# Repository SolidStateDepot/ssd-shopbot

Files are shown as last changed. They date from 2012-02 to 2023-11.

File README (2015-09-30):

Boulder Engineering Studio Shopbot - LinuxCNC config notes

The BES Shopbot is based on a Shopbot PRS-Alpha 96x60.  The Shopbot
Assembly Manual is here:

    http://www.shopbotdocs.com/PRS-Assembly-Manual.html

The BES Shopbot is an XYZX gantry machine.  All four joint motors are
steppers with encoder feedback.

The BES Shopbot uses a Mesa 5i23.  It uses three daughter cards:

P2: 7i47 (12-channel RS-422 serial communication interface)

    IO 000 (P2-01): StepGen #0, pin Step (Output)
    IO 001 (P2-03): StepGen #0, pin Direction (Output)
    IO 002 (P2-05): StepGen #1, pin Step (Output)
    IO 003 (P2-07): StepGen #1, pin Direction (Output)
    IO 004 (P2-09): Encoder #0, pin A (Input)
    IO 005 (P2-11): Encoder #2, pin A (Input)
    IO 006 (P2-13): Encoder #0, pin B (Input)
    IO 007 (P2-15): Encoder #2, pin B (Input)
    IO 008 (P2-17): Encoder #0, pin Index (Input)
    IO 009 (P2-19): Encoder #2, pin Index (Input)
    IO 010 (P2-21): Encoder #1, pin A (Input)
    IO 011 (P2-23): Encoder #3, pin A (Input)
    IO 012 (P2-25): Encoder #1, pin B (Input)
    IO 013 (P2-27): Encoder #3, pin B (Input)
    IO 014 (P2-29): Encoder #1, pin Index (Input)
    IO 015 (P2-31): Encoder #3, pin Index (Input)
    IO 016 (P2-33): StepGen #2, pin Step (Output)
    IO 017 (P2-35): StepGen #2, pin Direction (Output)
    IO 018 (P2-37): StepGen #3, pin Step (Output)
    IO 019 (P2-39): StepGen #3, pin Direction (Output)
    IO 020 (P2-41): PWMGen #0, pin Out0 (PWM or Up) (Output)
    IO 021 (P2-43): PWMGen #0, pin Out1 (Dir or Down) (Output)
    IO 022 (P2-45): PWMGen #1, pin Out0 (PWM or Up) (Output)
    IO 023 (P2-47): PWMGen #1, pin Out1 (Dir or Down) (Output)

P3: 7i37 (isolated digital I/O)
| IO  | Conn  | Module | Use                                                         | 7i37 pin
+-----+----------------+-------------------------------------------------------------+-----------
| 024 | P3-01 | IOPort | x1 prox input (home, +limit, -limit, negated)               | 1: in0
| 025 | P3-03 | IOPort |                                                             | 3: in1
| 026 | P3-05 | IOPort | y prox input (home, +limit, -limit, negated)                | 5: in2
| 027 | P3-07 | IOPort |                                                             | 7: in3
| 028 | P3-09 | IOPort | z prox input (home, +limit, -limit, negated)                | 9: in4
| 029 | P3-11 | IOPort |                                                             | 11: in5
| 030 | P3-13 | IOPort | x2 prox input (home, +limit, -limit, negated)               | 13: in6
| 031 | P3-15 | IOPort |                                                             | 15: in7
| 032 | P3-17 | IOPort | (input is dead)                                             | 17: in8
| 033 | P3-19 | IOPort | (input is dead)                                             | 19: in9
| 034 | P3-21 | IOPort | (input is dead)                                             | 21: in10
| 035 | P3-23 | IOPort | (input is dead)                                             | 23: in11
| 036 | P3-25 | IOPort | (input is dead)                                             | 25: in12
| 037 | P3-27 | IOPort | pendant estop input (no key switch)                         | 27: in13
| 038 | P3-29 | IOPort | pendant estop input with key switch                         | 29: in14
| 039 | P3-31 | IOPort |                                                             | 31: in15
| 040 | P3-33 | IOPort |                                                             | 33: out0
| 041 | P3-35 | IOPort |                                                             | 35: out1
| 042 | P3-37 | IOPort |                                                             | 37: out2
| 043 | P3-39 | IOPort |                                                             | 39: out3
| 044 | P3-41 | IOPort | motion motor contactor                                      | 41: out4
| 045 | P3-43 | IOPort |                                                             | 43: out5
| 046 | P3-45 | IOPort | spindle motor contactor                                     | 45: out6
| 047 | P3-47 | IOPort |                                                             | 47: out7
|     | P3-49 |        |                                                             | 49: +5
+-----+----------------+-------------------------------------------------------------+-----------

P4: 7i42 (over/under voltage protected break-out board)
| IO  | Conn  | Module | Use                                                         | 7i42 pin
+-----+----------------+-------------------------------------------------------------+-----------
| 048 | P4-01 | IOPort |                                                             | io0
| 049 | P4-03 | IOPort |                                                             | io1
| 050 | P4-05 | IOPort |                                                             | io2
| 051 | P4-07 | IOPort |                                                             | io3
| 052 | P4-09 | IOPort |                                                             | io4
| 053 | P4-11 | IOPort |                                                             | io5
| 054 | P4-13 | IOPort |                                                             | io6
| 055 | P4-15 | IOPort |                                                             | io7
| 056 | P4-17 | IOPort |                                                             | io8
| 057 | P4-19 | IOPort |                                                             | io9
| 058 | P4-21 | IOPort |                                                             | io10
| 059 | P4-23 | IOPort |                                                             | io11
| 060 | P4-25 | IOPort |                                                             | io12
| 061 | P4-27 | IOPort |                                                             | io13
| 062 | P4-29 | IOPort |                                                             | io14
| 063 | P4-31 | IOPort |                                                             | io15
| 064 | P4-33 | IOPort | 1-phase contactor closed                                    | io16
| 065 | P4-35 | IOPort | pendant green momentary button (not working)                | io17
| 066 | P4-37 | IOPort | 3-phase contactor closed                                    | io18
| 067 | P4-39 | IOPort | pendant blue momentary button (release=True, push=False)    | io19
| 068 | P4-41 | IOPort | zero plate                                                  | io20
| 069 | P4-43 | IOPort |                                                             | io21
| 070 | P4-45 | IOPort |                                                             | io22
| 071 | P4-47 | IOPort |                                                             | io23
+-----+----------------+-------------------------------------------------------------+-----------

Steppers are labeled ASM98AA-T7.2

Stepper amps are labeled ASD30A-A

The stepper amps take 1625 steps/revolution of the stepper motor,
which means 1625*7.2 steps per revolution of the output shaft of the
transmission.

1 encoder line per step, so 4 encoder edges per step

2.5 teeth/cm on the rack

X, Y1, and Y2 have 30 teeth on the pinion gear

Z has 25 teeth on the pinion

Table

For the table, cut one ~33" x 8' strip of 3/4" ply, and bolt it to the left
(-X) side of the frame.

Spindle

    to turn on spindle:

        spindle key in engaged position in spindle interlock (on
        control box)

        push "Spindle Power" button on VCP

        set spindle speed with S word, 4k-18k

        M3

    Each day, when first starting to use the spindle, run the
    warmup-spindle program.  Power on the machine and home it, then
    switch to the MDI tab and run "o<warmup-spindle> call".  This will
    turn on the spindle and ramp the spind speed up from 4k rpm to 18k
    rpm over 10 minutes.

The Mesa 5i23 hardware I/O card
will be loaded with firmware designation: SVST8_4
and has 72 I/O pins

Mesa 5i20 connector 2 

pin# 0 (type HDW Encoder-B)               
    connected to signal:'x-encoder-b'

pin# 1 (type HDW Encoder-A)               
    connected to signal:'x-encoder-a'

pin# 2 (type HDW Encoder-B)               
    connected to signal:'a-encoder-b'

pin# 3 (type HDW Encoder-A)               
    connected to signal:'a-encoder-a'

pin# 4 (type HDW Encoder-I)               
    connected to signal:'x-encoder-i'

pin# 5 (type HDW Encoder-I)               
    connected to signal:'a-encoder-i'

pin# 6 (type HDW PWM Gen-P)               
    connected to signal:'x-pwm-pulse'

pin# 7 (type HDW PWM Gen-P)               
    connected to signal:'a-pwm-pulse'

pin# 8 (type HDW PWM Gen-D)               
    connected to signal:'x-pwm-dir'

pin# 9 (type HDW PWM Gen-D)               
    connected to signal:'a-pwm-dir'

pin# 10 (type HDW PWM Gen-E)               
    connected to signal:'x-pwm-enable'

pin# 11 (type HDW PWM Gen-E)               
    connected to signal:'a-pwm-enable'

pin# 12 (type HDW Encoder-B)               
    connected to signal:'y-encoder-b'

pin# 13 (type HDW Encoder-A)               
    connected to signal:'y-encoder-a'

pin# 14 (type HDW Encoder-B)               
    connected to signal:'z-encoder-b'

pin# 15 (type HDW Encoder-A)               
    connected to signal:'z-encoder-a'

pin# 16 (type HDW Encoder-I)               
    connected to signal:'y-encoder-i'

pin# 17 (type HDW Encoder-I)               
    connected to signal:'z-encoder-i'

pin# 18 (type HDW PWM Gen-P)               
    connected to signal:'y-pwm-pulse'

pin# 19 (type HDW PWM Gen-P)               
    connected to signal:'z-pwm-pulse'

pin# 20 (type HDW PWM Gen-D)               
    connected to signal:'y-pwm-dir'

pin# 21 (type HDW PWM Gen-D)               
    connected to signal:'z-pwm-dir'

pin# 22 (type HDW PWM Gen-E)               
    connected to signal:'y-pwm-enable'

pin# 23 (type HDW PWM Gen-E)               
    connected to signal:'z-pwm-enable'

Mesa 5i20 connector 3 

pin# 0 (type GPIO Input)               
    connected to signal:'both-home-x'

pin# 1 (type GPIO Input)               
    connected to signal:'both-home-a'

pin# 2 (type GPIO Input)               
    connected to signal:'both-home-y'

pin# 3 (type GPIO Input)               
    connected to signal:'both-home-y'

pin# 4 (type GPIO Input)               
    connected to signal:'estop-ext'

pin# 5 (type GPIO Input)               
    connected to signal:'din-00'

pin# 6 (type GPIO Input)               
    connected to signal:'din-01'

pin# 7 (type HDW PWM Gen-P)               
    connected to signal:'unused-pwm'

pin# 8 (type GPIO Input)               
    connected to signal:'din-03'

pin# 9 (type HDW PWM Gen-D)               
    connected to signal:'unused-pwm'

pin# 10 (type GPIO Input)               
    connected to signal:'unused-input'

pin# 11 (type HDW PWM Gen-E)               
    connected to signal:'unused-pwm'

pin# 12 (type GPIO Input)               
    connected to signal:'unused-input'

pin# 13 (type GPIO Input)               
    connected to signal:'unused-input'

pin# 14 (type GPIO Input)               
    connected to signal:'unused-input'

pin# 15 (type GPIO Input)               
    connected to signal:'unused-input'

pin# 16 (type GPIO Output)               
    connected to signal:'unused-output'

pin# 17 (type GPIO Output)               
    connected to signal:'unused-output'

pin# 18 (type GPIO Output)               
    connected to signal:'unused-output'

pin# 19 (type GPIO Output)               
    connected to signal:'unused-output'

pin# 20 (type GPIO Output)               
    connected to signal:'unused-output'

pin# 21 (type GPIO Output)               
    connected to signal:'unused-output'

pin# 22 (type GPIO Output)               
    connected to signal:'unused-output'

pin# 23 (type GPIO Output)               
    connected to signal:'unused-output'

Mesa 5i20 connector 4 

pin# 0 (type HDW Step Gen-A)               
    connected to signal:'unused-stepgen'

pin# 1 (type HDW Step Gen-B)               
    connected to signal:'unused-stepgen'

pin# 2 (type GPIO Input)               
    connected to signal:'unused-input'

pin# 3 (type GPIO Input)               
    connected to signal:'unused-input'

pin# 4 (type GPIO Input)               
    connected to signal:'unused-input'

pin# 5 (type GPIO Input)               
    connected to signal:'unused-input'

pin# 6 (type HDW Step Gen-A)               
    connected to signal:'unused-stepgen'

pin# 7 (type HDW Step Gen-B)               
    connected to signal:'unused-stepgen'

pin# 8 (type GPIO Input)               
    connected to signal:'unused-input'

pin# 9 (type GPIO Input)               
    connected to signal:'unused-input'

pin# 10 (type GPIO Input)               
    connected to signal:'unused-input'

pin# 11 (type GPIO Input)               
    connected to signal:'unused-input'

pin# 12 (type HDW Step Gen-A)               
    connected to signal:'unused-stepgen'

pin# 13 (type HDW Step Gen-B)               
    connected to signal:'unused-stepgen'

pin# 14 (type GPIO Input)               
    connected to signal:'unused-input'

pin# 15 (type GPIO Input)               
    connected to signal:'unused-input'

pin# 16 (type GPIO Output)               
    connected to signal:'unused-output'

pin# 17 (type GPIO Output)               
    connected to signal:'unused-output'

pin# 18 (type HDW Step Gen-A)               
    connected to signal:'unused-stepgen'

pin# 19 (type HDW Step Gen-B)               
    connected to signal:'unused-stepgen'

pin# 20 (type GPIO Output)               
    connected to signal:'unused-output'

pin# 21 (type GPIO Output)               
    connected to signal:'unused-output'

pin# 22 (type GPIO Output)               
    connected to signal:'unused-output'

pin# 23 (type GPIO Output)               
    connected to signal:'unused-output'

VFD:

      Yaskawa V7-4X

      There's an arduino in there...

      Dan says: We are running in 2-wire mode (i think 5-33) and the
      speed is controlled by "Frequency Reference via Puls Train Input"
      (page 5-12).

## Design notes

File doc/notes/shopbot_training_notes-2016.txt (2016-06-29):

Shopbot tips

-World mode / joint
-Prefer MDI mode, and slow review of command input
-Be aware of G64 setting, tolerance that is too large will "cut-corners" and jeopardize fixutring, etc.
-Use a software stop when possible, E-stop when necessary
-The machine is not true
-Backlash is not well compensated
-Keep bystanders away from the machine
-Be aware of incremental (G91) vs absolute (G90) distance modes, misunderstanding can be catastrophic
-Be aware of your coordinate system, and the potential to accidentally command incorrect coordinate system motion
-

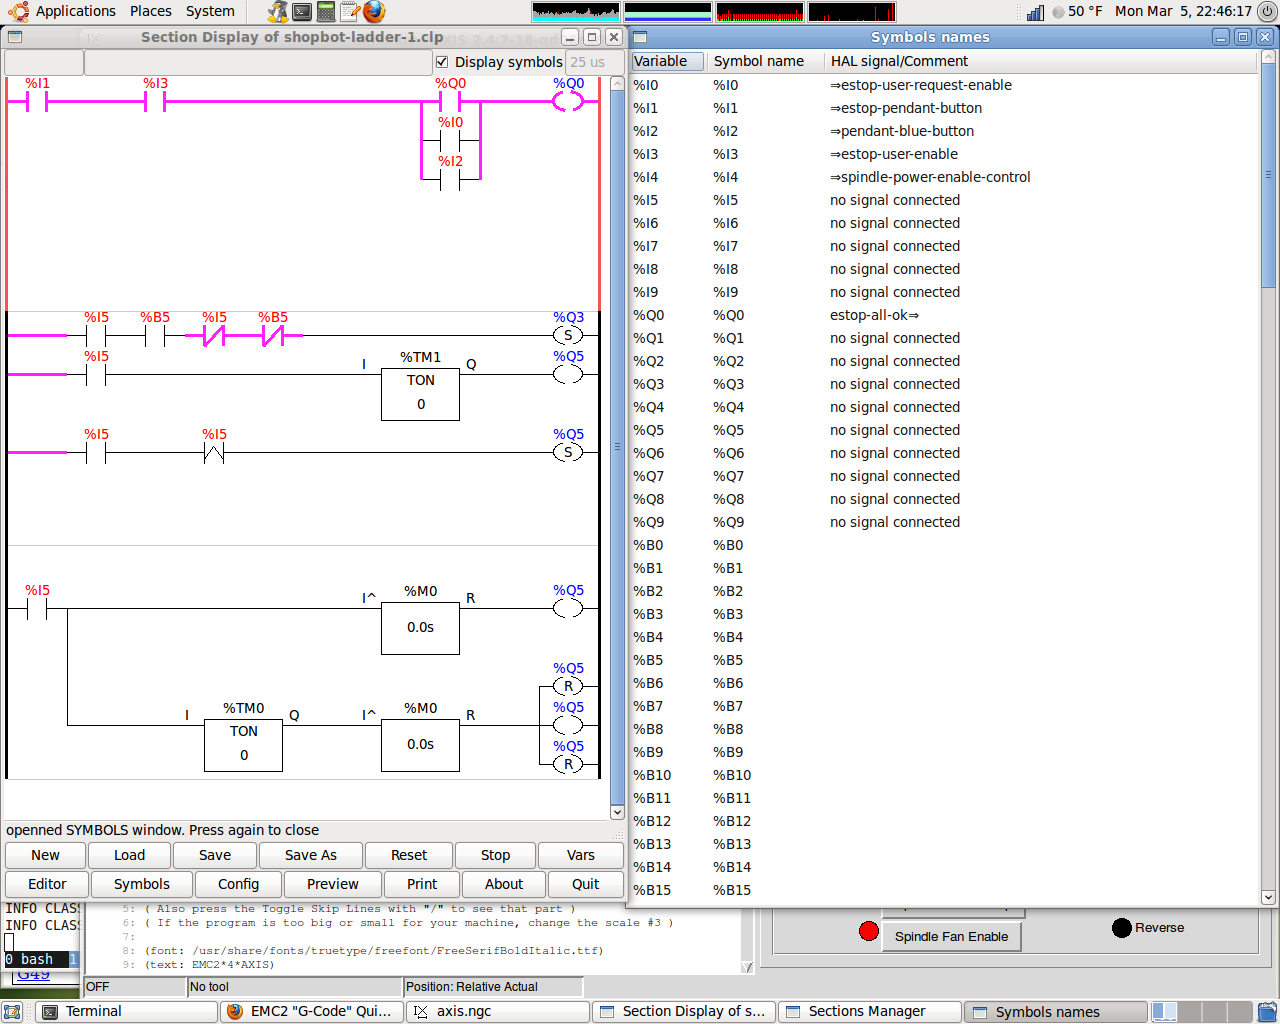
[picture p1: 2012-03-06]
ladder.png

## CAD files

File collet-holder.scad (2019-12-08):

rads = [0.125,0.15625,0.1875,0.21875,0.25,0.28125,0.3125,0.34375,0.375,0.40625,0.4375,0.5,0.625];

locs = [[0,0,0],
[1,0,0],
[2,0,0],
[3,0,0],
[0,-1,0],
[1,-1,0],
[2,-1,0],
[3,-1,0],
[0,-2,0],
[1,-2,0],
[2,-2,0],
[3,-2,0],
[0,-3,0]];

for (i = [0:1:len(rads)-1]) {
  translate(locs[i])
  cylinder(h=0.5,r=rads[i]*0.5,
    $fn=48);
};

translate([-1,-4,-0.25])
cube([5,5,0.25]);

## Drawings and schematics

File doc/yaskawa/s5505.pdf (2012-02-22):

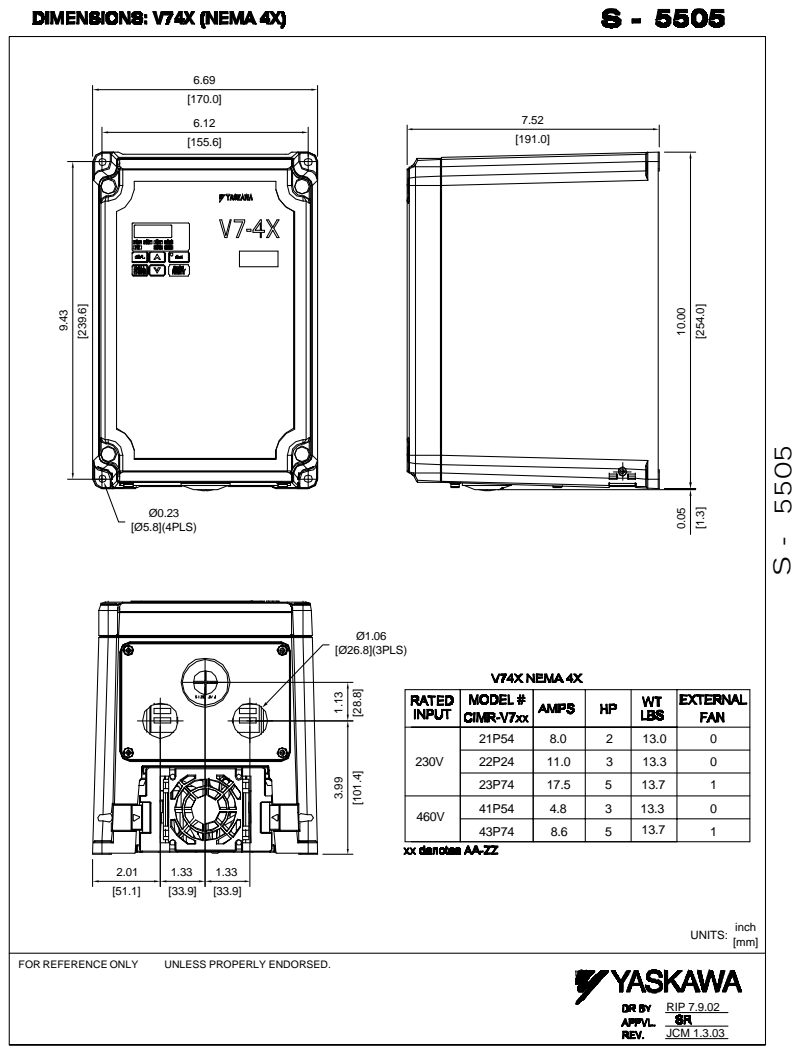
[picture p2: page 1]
RIP 7.9.02; [mm] UNITS:; JCM 1.3.03

FOR REFERENCE ONLY

UNLESS PROPERLY ENDORSED.

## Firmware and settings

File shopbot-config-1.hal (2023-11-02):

###EMC2.4.2 Configuration for Shopbot-Ultra, developed at Boulder Engineering Studio, July 2010

# ###################################
# BEGIN Core EMC/HAL Loads
# ###################################

# This machine uses Gantry kinematics.
# Joint 1 and joint 3 are motors on either side of the gantry, driving the gantry along the Y axis
# Joint 0 is a motor on the gantry, driving the spindle sled side to side on the gantry along the X axis
# Joint 2 is a motor on the spindle sled, driving the spindle along the Z axis
loadrt [KINS]KINEMATICS coordinates=xyzy kinstype=BOTH
#autoconverted  gantrykins coordinates=xyzy

# Load the realtime portion of classic ladder
loadrt classicladder_rt numRungs=12 numBits=20 numWords=4 numTimers=5 numMonostables=2 numPhysInputs=16 numPhysOutputs=16 numArithmExpr=4 numSections=4
# Loader the userspace portion of Classic Ladder to silently load the program
loadusr classicladder --modmaster --nogui shopbot-ladder-1.clp

# motion controller, get name and thread periods from ini file
loadrt [EMCMOT]EMCMOT servo_period_nsec=[EMCMOT]SERVO_PERIOD num_joints=[KINS]JOINTS

# hostmot2 driver
loadrt hostmot2
# load low-level driver
loadrt hm2_pci config="firmware=hm2/5i23/SVST2_4_7I47.BIT num_encoders=4 num_pwmgens=2 num_stepgens=4" 
setp hm2_5i23.0.pwmgen.pwm_frequency 100000
setp hm2_5i23.0.pwmgen.pdm_frequency 100000


#
# build servo thread
#

addf hm2_5i23.0.read servo-thread

# linuxcnc 2.7 pets the watchdog in hm2_write
#addf hm2_5i23.0.pet_watchdog  servo-thread

addf conv-s32-float.0 servo-thread
addf conv-s32-float.1 servo-thread
addf conv-s32-float.2 servo-thread
addf conv-s32-float.3 servo-thread
addf conv-s32-float.4 servo-thread
addf conv-s32-float.5 servo-thread
addf conv-s32-float.6 servo-thread
addf conv-s32-float.7 servo-thread

addf sum2.0 servo-thread
addf sum2.1 servo-thread
addf sum2.2 servo-thread
addf sum2.3 servo-thread

addf toggle.0 servo-thread
addf toggle.1 servo-thread
addf toggle.4 servo-thread
addf toggle.5 servo-thread
addf toggle.6 servo-thread

addf and2.zero-all    servo-thread
addf and2.zero-x      servo-thread
addf and2.zero-y      servo-thread
addf and2.zero-z      servo-thread
addf and2.zero-plate  servo-thread

addf or2.spindle-fan-power servo-thread

addf classicladder.0.refresh               servo-thread

addf motion-command-handler servo-thread
addf motion-controller servo-thread

# these two take the spindle speed command from motion and cook it for the arduino
addf scale.spindle-speed servo-thread
addf abs.spindle-speed servo-thread

addf hm2_5i23.0.write         servo-thread


# ################################################
# External Output Signals
# ################################################
#Contactor control for Stepper power
net contactor-stepper-control     <=  joint.0.amp-enable-out
net contactor-stepper-control     =>  hm2_5i23.0.gpio.044.out
net contactor-stepper-control     =>  hm2_5i23.0.stepgen.01.enable
setp hm2_5i23.0.gpio.044.is_output 1
setp hm2_5i23.0.gpio.044.is_opendrain 1
setp hm2_5i23.0.gpio.044.invert_output 1
#setp hm2_5i23.0.gpio.044.out 1

#Contactor control for Spindle power
#net contactor-spindle-control     <=  joint.1.amp-enable-out
#net contactor-spindle-control     =>  hm2_5i23.0.gpio.046.out
setp hm2_5i23.0.gpio.046.is_output 1
setp hm2_5i23.0.gpio.046.is_opendrain 1
setp hm2_5i23.0.gpio.046.invert_output 1

#Spindle Power Enable
net spindle-power-enable-control => hm2_5i23.0.gpio.046.out

#Spindle Fan Control
net spindle-fan-control =>  hm2_5i23.0.gpio.047.out
setp hm2_5i23.0.gpio.047.is_output 1
setp hm2_5i23.0.gpio.047.is_opendrain 1
setp hm2_5i23.0.gpio.047.invert_output 1

#Spindle Forward / Reverse Control
#net spindle-forward-control => hm2_5i23.0.gpio.041.out
setp hm2_5i23.0.gpio.041.is_output 1
setp hm2_5i23.0.gpio.041.is_opendrain 1
setp hm2_5i23.0.gpio.041.invert_output 1
#net spindle-reverse-control => hm2_5i23.0.gpio.043.out
setp hm2_5i23.0.gpio.043.is_output 1
setp hm2_5i23.0.gpio.043.is_opendrain 1
setp hm2_5i23.0.gpio.043.invert_output 1

#Mist Coolant Control
#net mist-control     =>  hm2_5i23.0.gpio.043.out
#setp hm2_5i23.0.gpio.043.is_output 1


#Stepper Driver Digital I/O
net alarm-clear-x     =>  hm2_5i23.0.gpio.054.out
setp hm2_5i23.0.gpio.054.is_output 1

net alarm-clear-y1     =>  hm2_5i23.0.gpio.050.out
setp hm2_5i23.0.gpio.050.is_output 1

net alarm-clear-z     =>  hm2_5i23.0.gpio.058.out
setp hm2_5i23.0.gpio.058.is_output 1

net alarm-clear-y2     =>  hm2_5i23.0.gpio.062.out
setp hm2_5i23.0.gpio.056.is_output 1


net stepper-windings-off-x     =>  hm2_5i23.0.gpio.055.out
setp hm2_5i23.0.gpio.055.is_output 1

net stepper-windings-off-y1     =>  hm2_5i23.0.gpio.051.out
setp hm2_5i23.0.gpio.051.is_output 1

net stepper-windings-off-z     =>  hm2_5i23.0.gpio.059.out
setp hm2_5i23.0.gpio.059.is_output 1

net stepper-windings-off-y2     =>  hm2_5i23.0.gpio.063.out
setp hm2_5i23.0.gpio.063.is_output 1


# ################################################
# External Input Signals
# ################################################
#Contactor status for Stepper and Spindle power
net contactor-stepper-status     <=  hm2_5i23.0.gpio.064.in
net contactor-spindle-status     <=  hm2_5i23.0.gpio.066.in


# Control Pendant
# One of the two control pendants has two extra momentary buttons (in
# addition to the latching red estop button).
# The green button doesn't seem to be wired up...

net pendant-green-button <= hm2_5i23.0.gpio.065.in_not
net pendant-blue-button  <= hm2_5i23.0.gpio.067.in_not


#Spindle Key Switch
net spindle-key-switch    <=  hm2_5i23.0.gpio.038.in_not
#net spindle-key-switch    =>  classicladder.0.in-05

#Zero Plate
#net probe-in <=  hm2_5i23.0.gpio.068.in_not


#
# Prox limit/home sensors
#

net prox-x  <= hm2_5i23.0.gpio.026.in_not
net prox-x  => joint.0.home-sw-in joint.0.neg-lim-sw-in joint.0.pos-lim-sw-in

net prox-y1 <= hm2_5i23.0.gpio.024.in_not
net prox-y1 => joint.1.home-sw-in joint.1.neg-lim-sw-in joint.1.pos-lim-sw-in

net prox-z  <= hm2_5i23.0.gpio.028.in_not
net prox-z  => joint.2.home-sw-in joint.2.pos-lim-sw-in joint.2.neg-lim-sw-in

net prox-y2 <= hm2_5i23.0.gpio.030.in_not 
net prox-y2 => joint.3.home-sw-in joint.3.neg-lim-sw-in joint.3.pos-lim-sw-in


#Stepper Driver Digital I/O #run all of these into estop chain
net alarm-x     <=  hm2_5i23.0.gpio.052.in
net alarm-y1    <=  hm2_5i23.0.gpio.048.in
net alarm-z     <=  hm2_5i23.0.gpio.056.in
net alarm-y2    <=  hm2_5i23.0.gpio.060.in

#net alarm-x1     =>  classicladder.0.in-05
#net alarm-y     =>  classicladder.0.in-06
#net alarm-z     =>  classicladder.0.in-07
#net alarm-x2     =>  classicladder.0.in-08




# ######################################################
# Axis-of-motion Specific Configs (not the GUI)
# ######################################################

# axis enable chain
#net axis-enable-chain-x  joint.0.amp-enable-out => hm2_5i23.0.stepgen.01.enable
net axis-enable-chain-y1 joint.1.amp-enable-out => hm2_5i23.0.stepgen.00.enable
net axis-enable-chain-z  joint.2.amp-enable-out => hm2_5i23.0.stepgen.02.enable
net axis-enable-chain-y2 joint.3.amp-enable-out => hm2_5i23.0.stepgen.03.enable

# encoder feedback signals
setp hm2_5i23.0.encoder.01.scale [JOINT_0]INPUT_SCALE
net x-encoder-pos <= hm2_5i23.0.encoder.01.position
net x-encoder-pos => joint.0.motor-pos-fb
net x-encoder-count <= hm2_5i23.0.encoder.01.count

setp hm2_5i23.0.encoder.00.scale [JOINT_1]INPUT_SCALE
net y1-encoder-pos <= hm2_5i23.0.encoder.00.position
net y1-encoder-pos => joint.1.motor-pos-fb
net y1-encoder-count <= hm2_5i23.0.encoder.00.count

setp hm2_5i23.0.encoder.02.scale [JOINT_2]INPUT_SCALE
net z-encoder-pos <= hm2_5i23.0.encoder.02.position
net z-encoder-pos => joint.2.motor-pos-fb
net z-encoder-count <= hm2_5i23.0.encoder.02.count

setp hm2_5i23.0.encoder.03.scale [JOINT_3]INPUT_SCALE
net y2-encoder-pos <= hm2_5i23.0.encoder.03.position
net y2-encoder-pos => joint.3.motor-pos-fb
net y2-encoder-count <= hm2_5i23.0.encoder.03.count




# position command
net x.pos-cmd  joint.0.motor-pos-cmd => hm2_5i23.0.stepgen.01.position-cmd

net y1.pos-cmd joint.1.motor-pos-cmd => hm2_5i23.0.stepgen.00.position-cmd

net z.pos-cmd  joint.2.motor-pos-cmd => hm2_5i23.0.stepgen.02.position-cmd

net y2.pos-cmd joint.3.motor-pos-cmd => hm2_5i23.0.stepgen.03.position-cmd


#Axis Jogging Settings
setp joint.0.jog-vel-mode	1
setp joint.1.jog-vel-mode	1
setp joint.2.jog-vel-mode	1
setp joint.3.jog-vel-mode	1	

# Stepgen parameters
setp hm2_5i23.0.stepgen.01.dirsetup        [JOINT_0]DIRSETUP
setp hm2_5i23.0.stepgen.01.dirhold         [JOINT_0]DIRHOLD
setp hm2_5i23.0.stepgen.01.steplen         [JOINT_0]STEPLEN
setp hm2_5i23.0.stepgen.01.stepspace       [JOINT_0]STEPSPACE
setp hm2_5i23.0.stepgen.01.position-scale  [JOINT_0]OUTPUT_SCALE
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

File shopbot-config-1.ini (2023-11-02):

# Modified 	2021-04-10 by Jacob to lessen acceleration in order to avoid errors was 35, now 25
#		2020-12-02 by Rose to widen override range
#		2020-09-29 by Jacob to set default folder to the current user's
#		2020-09-27 by Jacob to decrease soft limits on X, Y, and Z to avoid hard limit on jogs.
#		2020-08-20 by Marshall to correct X and Y scaling:
#	Root of problem: rack pitch used in original calc (2.5 teeth/cm) is close, but not accurate.
#	I never figured out the exact pitch, and instead adjusted by a factor based on measured error.
#	Joints 0, 1 and 3 (X, Y1 and Y2) OUTPUT_SCALE and INPUT_SCALE updated.
#		Old OUTPUT_SCALE: 2476.5 ---> New: 2483 steps/inch.
#		Old INPUT_SCALE: 9906 ---> New: 9932 steps/inch.
# This config file was created 2016-02-09 22:05:16.594945 by the update_ini script
# The original config files may be found in the /home/seb/bes-shopbot/shopbot-config-1.old directory

###EMC2.4.2 Configuration for Shopbot-Ultra, developed at Boulder Engineering Studio, July 2010

[EMC]
# The version string for this INI file.
VERSION = 1.1

MACHINE = Boulder Engineering Studio Shopbot Ultra
#DEBUG = 0
DEBUG = 0x7fffffff

[DISPLAY]
DISPLAY = axis
# Cycle time, in seconds, that display will sleep between polls
CYCLE_TIME =		0.050
#- Initial display setting for position, RELATIVE or MACHINE
POSITION_OFFSET = RELATIVE
#- Initial display setting for position, COMMANDED or ACTUAL
POSITION_FEEDBACK = ACTUAL
#+ Highest value that will be allowed for feed override, 1.0 = 100%
MAX_FEED_OVERRIDE = 2.000000
MAX_SPINDLE_OVERRIDE = 1.000000
MIN_SPINDLE_OVERRIDE = 0.200000
INTRO_GRAPHIC = emc2.gif
INTRO_TIME = 4
#PROGRAM_PREFIX = /opt/ssd-shopbot/gcode
PROGRAM_PREFIX = ~

INCREMENTS = 1.000, 0.100, 0.010, 0.001

DEFAULT_LINEAR_VELOCITY = 1.5
MAX_LINEAR_VELOCITY = 18
MIN_LINEAR_VELOCITY = 0.5
EDITOR = gedit
TOOL_EDITOR = gvim
GEOMETRY = xyz
PYVCP = panel.xml

[FILTER]
PROGRAM_EXTENSION = .png,.gif,.jpg Greyscale Depth Image
PROGRAM_EXTENSION = .py Python Script
PROGRAM_EXTENSION = .NGC XYZ Post Processor
png = image-to-gcode
gif = image-to-gcode
jpg = image-to-gcode
py = python

[RS274NGC]
PARAMETER_FILE = emc.var
SUBROUTINE_PATH = /opt/ssd-shopbot/gcode
RS274NGC_STARTUP_CODE = g80 g17 g20 g40 g49 g54 g64p0.001 g90 g91.1 g94 g99


[EMCMOT]
EMCMOT = motmod
COMM_TIMEOUT = 1.0
COMM_WAIT = 0.010
SERVO_PERIOD = 1000000

[TASK]
TASK = milltask
CYCLE_TIME = 0.010

[HAL]
# The run script first uses halcmd to execute any HALFILE
# files, and then to execute any individual HALCMD commands.

# HALUI to interact with NML
# Run before any other HALFILE
HALUI = halui
HALFILE = load-shared-modules.hal
HALFILE = shopbot-config-1.hal
HALFILE = manual-tool-change.hal
#HALFILE = shuttlexpress.hal
POSTGUI_HALFILE = custom_postgui.hal

[HALUI]
MDI_COMMAND = G92 x0 y0 z0
MDI_COMMAND = G92 x0
MDI_COMMAND = G92 y0
MDI_COMMAND = G92 z0
MDI_COMMAND = G53 G0 x0 y0 z0 #Home Preset 1
MDI_COMMAND = G53 G0 #Home Preset 2
MDI_COMMAND = G53 G0 #Home Preset 3
MDI_COMMAND = G53 G0 #Home Preset 4
MDI_COMMAND = G53 G0 #Home Preset 5
MDI_COMMAND = G53 G0 #Home Preset 6
MDI_COMMAND = G53 G0 #Home Preset 7
MDI_COMMAND = G53 G0 #Home Preset 8
#MDI_COMMAND = o<countersink-for-table> call
MDI_COMMAND = o<spindle-up> call
MDI_COMMAND = o<present-spindle> call
MDI_COMMAND = o<vacuum-the-table> call
MDI_COMMAND = o<warmup-spindle> call


[TRAJ]
AXES = 3
JOINTS = 4
COORDINATES = X Y Z Y
HOME = 0 0 0 0

LINEAR_UNITS = inch
ANGULAR_UNITS = degree

CYCLE_TIME = 0.010

DEFAULT_VELOCITY = 2

# nontrivkins machines need this for world-mode jogs
DEFAULT_ACCELERATION = 25

MAX_LINEAR_VELOCITY = 12

MAX_ACCELERATION = 25

NO_FORCE_HOMING = 0

# Don't store the position across restarts of LinuxCNC, since the Shopbot
# is so easy to move when it's powered off, which makes a lie of the
# stored position.
#POSITION_FILE = position.txt


[EMCIO]
EMCIO = io
CYCLE_TIME = 0.100
TOOL_TABLE = tool.tbl
TOOL_CHANGE_WITH_SPINDLE_ON = 0
TOOL_CHANGE_QUILL_UP = 1
TOOL_CHANGE_AT_G30 = 0
TOOL_CHANGE_POSITION = 30 12 0


#********************
# Axis X (Joint 0)
#********************

[KINS]
KINEMATICS =  trivkins
JOINTS = 4


[AXIS_A]
MIN_LIMIT=-0.250
MAX_LIMIT=102.250
MAX_VELOCITY = 12
MAX_ACCELERATION = 25

[AXIS_X]
MIN_LIMIT = 0.000
MAX_LIMIT = 61.250
MAX_VELOCITY = 12
MAX_ACCELERATION = 25

[JOINT_0]

TYPE = LINEAR

# stepper scale in steps/inch
# the funky Shopbot stepper motors have 11,700 steps/rev
# the X, Y1, and Y2 pinion gears have 30 teeth/rev
# the rack gear has 2.5 teeth/cm
# 11,700 steps/rev * 1/30 rev/teeth * 2.5 teeth/cm * 2.54 cm/inch
OUTPUT_SCALE = -2483

# encoder scale in edges/inch
# the encoder has 11,700 lines/rev, so it's the same math as the
# OUTPUT_SCALE above, except we get 4 encoder edges/line so this number is
# 4x higher
INPUT_SCALE = -9932

MAX_VELOCITY = 12

MAX_ACCELERATION = 25

OUTPUT_OFFSET = 0.0
MIN_LIMIT = 0.000
MAX_LIMIT = 61.40

FERROR = 0.50
MIN_FERROR = 0.050


#
# X joint homing
#

HOME_SEQUENCE = 1

HOME = 1.000
HOME_OFFSET = -0.750

HOME_SEARCH_VEL = -2.00000
HOME_LATCH_VEL = 0.250
HOME_FINAL_VEL = 2.5
HOME_USE_INDEX = No

HOME_IGNORE_LIMITS = YES

HOME_IS_SHARED = 0

VOLATILE_HOME = 1

#BACKLASH = 0.025

# these are in nanoseconds
DIRSETUP   =              1500
DIRHOLD    =              1500
STEPLEN    =              1500
STEPSPACE  =              2500


#********************
# Axis Y (Joint 1, aka Y1))
#********************
[AXIS_Y]
MIN_LIMIT = -0.250

# 102.851 is the physical end of travel
MAX_LIMIT = 102.250

MAX_VELOCITY = 12
MAX_ACCELERATION = 25

[JOINT_1]

TYPE = LINEAR

# stepper scale in steps/inch
OUTPUT_SCALE = 2483

# encoder scale in edges/inch
INPUT_SCALE = 9932

MAX_VELOCITY = 12
MAX_ACCELERATION = 25

OUTPUT_OFFSET = 0.0
MIN_LIMIT = -0.250

# 102.851 is the physical end of travel
MAX_LIMIT = 102.250

FERROR = 0.050
MIN_FERROR = 0.050


#
# Y1 joint homing
#

HOME_SEQUENCE = -1

HOME = 0.000
HOME_OFFSET = -0.350

HOME_SEARCH_VEL = -2
HOME_LATCH_VEL = 0.250
HOME_FINAL_VEL = 2.5
HOME_USE_INDEX = No

HOME_IGNORE_LIMITS = YES

HOME_IS_SHARED = 0

VOLATILE_HOME = 1

#BACKLASH = 0.0075

# these are in nanoseconds
DIRSETUP   =              1500
DIRHOLD    =              1500
STEPLEN    =              1500
STEPSPACE  =              2500


#********************
# Axis Z (Joint 2)
#********************
[AXIS_Z]
MIN_LIMIT = -7.500
MAX_LIMIT = 0.100
MAX_VELOCITY = 12
MAX_ACCELERATION = 25

[JOINT_2]

TYPE = LINEAR

# stepper scale in steps/inch
# the funky Shopbot stepper motors have 11,700 steps/rev
# the Z pinion gear has 25 teeth/rev
# the rack gear has 2.5 teeth/cm
# 11,700 steps/rev * 1/25 rev/teeth * 2.5 teeth/cm * 2.54 cm/inch
OUTPUT_SCALE = 2971.8

# encoder scale in edges/inch
# the encoder has 11,700 lines/rev, so it's the same math as the
# OUTPUT_SCALE above, except we get 4 encoder edges/line so this number is
# 4x higher
INPUT_SCALE = 11887.2

FERROR = 0.050
MIN_FERROR = 0.050

MAX_VELOCITY = 2
MAX_ACCELERATION = 25
OUTPUT_OFFSET = 0.0

MIN_LIMIT = -7.750
MAX_LIMIT = 0.100

#
# Z joint homing
#

HOME_SEQUENCE = 0

HOME = 0.000
HOME_OFFSET = 0.150

HOME_SEARCH_VEL = 1
HOME_LATCH_VEL = -0.25
HOME_FINAL_VEL = -2.5
HOME_USE_INDEX = NO

HOME_IGNORE_LIMITS = YES

HOME_IS_SHARED = 0

VOLATILE_HOME = 1

# these are in nanoseconds
DIRSETUP   =              1500
DIRHOLD    =              1500
STEPLEN    =              1500
STEPSPACE  =              2500


[JOINT_3]

TYPE = LINEAR

# stepper scale in steps/inch
OUTPUT_SCALE = 2483

# encoder scale in edges/inch
INPUT_SCALE = 9932

MAX_VELOCITY = 12
MAX_ACCELERATION = 25

OUTPUT_OFFSET = 0.0

MIN_LIMIT = -0.250

# 102.851 is the physical end of travel
MAX_LIMIT = 102.250

FERROR = 0.050
MIN_FERROR = 0.050


#
# Y2 joint homing

HOME_SEQUENCE = -1

HOME = 0.000
HOME_OFFSET = -0.350

HOME_SEARCH_VEL = -2
HOME_LATCH_VEL = 0.250
HOME_FINAL_VEL = 2.5
HOME_USE_INDEX = No

HOME_IGNORE_LIMITS = YES

HOME_IS_SHARED = 0

VOLATILE_HOME = 1


#BACKLASH = 0.0075

# these are in nanoseconds
DIRSETUP   =              1500
DIRHOLD    =              1500
STEPLEN    =              1500
STEPSPACE  =              2500

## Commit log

2012-02-18 initial commit of the config i found on the shopbot
    [Shopbot EMC Pins and Signals.xls, custom_postgui.hal, shopbot-config-1.hal]
2012-02-18 mesa manuals for the boards the shopbot uses
2012-02-18 whitespace changes only
    [shopbot-config-1.hal]
2012-02-18 add some comments on the kinematics
    [shopbot-config-1.hal]
2012-02-18 add some comments on joints/axes
2012-02-18 home switches are not shared
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2012-02-27 remove redundant settings from postgui hal file
    These already got set in the main hal file.
    [custom_postgui.hal]
2012-02-27 whitespace cleanups only
    [custom_postgui.hal, shopbot-config-1.hal]
2012-02-27 remove some unused realime components
    [shopbot-config-1.hal]
2012-02-27 move the hm2_write() function to be last
    The thread function order needs more work, there are other functions
    added later.
    [shopbot-config-1.hal]
2012-02-27 remove redundant pins in prox nets
    [shopbot-config-1.hal]
2012-02-27 fix a typo
    The axis 1 and 2 steplens are the same, so this typo wasnt causing any
    problems.
    [shopbot-config-1.hal]
2012-02-27 collect hm2 stepgen maxvels and maxaccels together
    This also gets rid of the explicit value for hm2 stepgen maxaccel, and
    instead uses 0, which means "let the trajectory planner choose"
    [shopbot-config-1.hal]
2012-02-27 add a comment
    [shopbot-config-1.hal]
2012-02-27 specify home pose for gantrykins
    I'm not sure if this is needed, but the manual seems to recommend it for
    nontrivkins machines.
2012-02-27 on toolchange, turn spindle off and move quill up
2012-02-27 use sane following error limits
    [shopbot-config-1.ini]
2012-02-27 fix homing and machine limits
    The machine now homes Z first, then X1, X2, and Y together second.
    The machine searches for its home switches at a safe slow speed, then
    backs off the switches very slowly, and rapids in a short distance from
    the switches and parks.
    The machine soft limits are .010 before the limit switches.
    HOME_OFFSET, HOME_SEARCH_VEL, and HOME_LATCH_VEL might want more tweaking,
    but this is a big improvement.
    [shopbot-config-1.ini]
2012-02-27 add a note about the watchdog timeout
    [shopbot-config-1.hal]
2012-02-27 remove unused comps from some nets
    [custom_postgui.hal]
2012-02-27 reorganize functions in servo thread
    Move all loading of realtime comps to the main hal file, and run the
    realtime functions in an order that makes sense.
    Also removed some unused realtime functions from the servo thread.
    [custom_postgui.hal, shopbot-config-1.hal]
2012-02-27 disable backlash comp for now
    [shopbot-config-1.ini]
2012-02-27 reduce accel, it's too much
    Accel etc still needs more tweaking, but these values work ok.
    [shopbot-config-1.ini]
2012-02-28 swap x and y axes
    major rototill...
    [custom_postgui.hal, shopbot-config-1.hal]
2012-02-28 swap x & y, get rid of encoder scale comp
    Use the encoders' built-in scales instead of separate scale components.
    Move encoder scale into the ini file.
    [custom_postgui.hal, shopbot-config-1.hal]
2012-02-29 simplified estop
    [shopbot-config-1.hal]
2012-03-06 clean up estop ladder
    Also add a png of the current ladder, for reference.
    [shopbot-config-1.hal]
2012-03-06 possibly bogus manual for steppers & amps
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2012-03-07 update a todo item now that X and Y are switched
2012-03-11 hook up z prox to -limit too
    [shopbot-config-1.hal]
2012-03-17 todo: better notes on joint-mode jogging problem
2012-03-17 clean up module loading
    * move module loading to a separate hal file
    * give (most) module instances names instead of numbers
    * remove unused modules & module instances
    [custom_postgui.hal, load-shared-modules.hal, shopbot-config-1.hal]
2012-03-17 add hal file for shuttlexpress
    This is currently somewhat broken; this hal file expects to be able to
    do both incremental and continuous jogs, but incremental jogs dont work
    on gantry machines...
    [load-shared-modules.hal, shuttlexpress.hal]
2012-03-17 machine coordinates for the reachable screw holes in the frame
2012-03-17 the shopbot is faster than my bridgeport!
    [shuttlexpress.hal]
2012-03-17 temporary hack to measure the holes in the frame
    [shuttlexpress.hal]
2012-03-17 more explicit [TRAJ] section
    This doesn't change linuxcnc's behavior at all
    [shopbot-config-1.ini]
2012-03-17 shuttlexpress driver shortcoming
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2012-03-18 a program to warm up the spindle to Dan's specification
2012-03-18 move some spindle info from Todo to Readme
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2012-03-18 another bug with the spindle
2012-03-20 turn off the shuttlexpress A-button hack
    [shuttlexpress.hal]
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2012-03-22 fix spindle on/off config
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2012-04-12 manual toolchange hal file
    [manual-tool-change.hal]
2012-05-15 improve pyvcp a bunch
    [custom_postgui.hal]
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2015-08-12 add a "warm up the spindle" button
    [custom_postgui.hal]
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2015-08-12 X has 0.025 inches of backlash
    [shopbot-config-1.ini]
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2015-08-12 update hal config to match new wiring
    [shopbot-config-1.hal]
2015-08-12 get rid of arduino spindle control (spindle control is broken now)
    [custom_postgui.hal]
2015-08-12 hm2 watchdog update for linuxcnc 2.7
    [shopbot-config-1.hal]
2015-08-12 spindle control via hy_vfd (spindle works again now)
    [custom_postgui.hal, shopbot-config-1.hal]
2015-08-12 use new spindle speed pins from hy_vfd
    [custom_postgui.hal, shopbot-config-1.hal]
2015-08-12 specify hy-vfd parameters on command-line
    [shopbot-config-1.hal]
2015-09-09 fixup SUBROUTINE_PATH for wheezy install
    [shopbot-config-1.ini]
2015-09-13 add spindle speed into to pyvcp
    [custom_postgui.hal]
2015-09-30 blew a couple of inputs on the 7i37, moved the estop wires
    [shopbot-config-1.hal]
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2016-02-10 straight from update_ini
    [shopbot-config-1.hal]
2016-05-04 switch from gantrykins to trivkins
    In joints_axes13, trivkins takes over the job of gantrykins.
    [shopbot-config-1.hal]
2016-05-04 greater separation between home/limit switches and soft limits
2016-05-11 increase cutter diameter for the facing mill we have
2016-05-11 update cut coordinates
    We moved the X soft limit, and the Z height changes each time you face
    the table.
2016-05-11 trace the outline at the end
    This gets rid of the scalloping due to the cutter radius.
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2016-08-17 temporary workaround for bug in check_config.tcl
    LinuxCNC Issue #145,
    https://github.com/LinuxCNC/linuxcnc/issues/145
    [shopbot-config-1.ini]
2017-06-21 switch spindle VFD from hy_vfd to the new hy_gt_vfd
    [custom_postgui.hal, shopbot-config-1.hal]
2017-07-19 set home final vel to something reasonable
    This seems to avoid following error at the start of the home final move.
    [shopbot-config-1.ini]
2017-07-19 point PROGRAM_PREFIX at the new path
    This makes the build-in mdi commands like "Warmup Spindle" work.
2019-12-07 add collet holder scan design
    [collet-holder.scad]
2019-12-07 clean up
    [collet-holder.scad]
2023-11-02 misc config changes not yet committed to git :-/
    [custom_postgui.hal, shopbot-config-1.hal]
2023-11-02 add a spindle on-time tracker
    [custom_postgui.hal, shopbot-config-1.hal]
2023-11-02 switch vacuum controller from wget to curl
    This command line does not save a file with the response from the Tasmota
    outlet, since we don't care about that.
2023-11-11 add air-filter-controller
    [custom_postgui.hal]
